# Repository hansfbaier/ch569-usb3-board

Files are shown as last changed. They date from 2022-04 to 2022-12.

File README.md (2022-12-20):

# CH569 USB3 Super Speed Board
USB3 super speed development board useful as FPGA expansion
based on the WCH-Tech CH569 chip.
It should also be possible to substitute the CH569 with a CH565 chip,
without further modifications.

### Board support
Open source development tools and board support package are available here:

https://github.com/orgs/hydrausb3/repositories

### Status
* rev0 tested and working
* rev1 tested and working
* rev2 tested and working. Passes stress test. Recommended!

NOTE: Both rev0 and rev1 have shown spurious transmission errors in USB3 stress tests.
Do not use for high performance duty. Adding a 100nF decoupling capacitor to the
3V3 pin of the crystal oscillator seemed to improve the situation significantly.





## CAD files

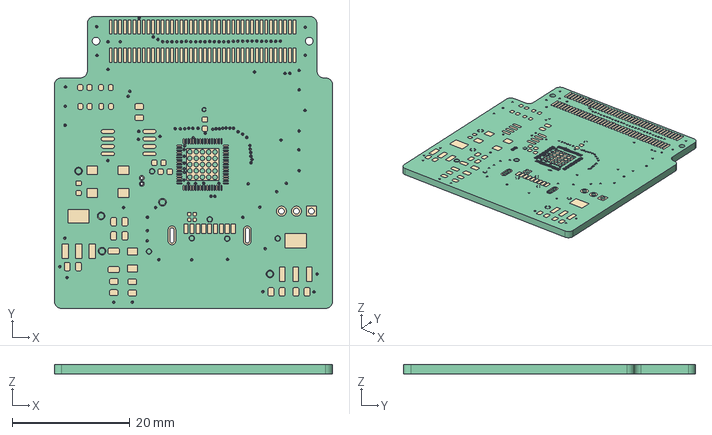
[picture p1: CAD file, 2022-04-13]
rev2/EdgeCuts.FCStd
47.3 x 49.6 x 1.62 mm
Pcb_12c2
topPads_12c2

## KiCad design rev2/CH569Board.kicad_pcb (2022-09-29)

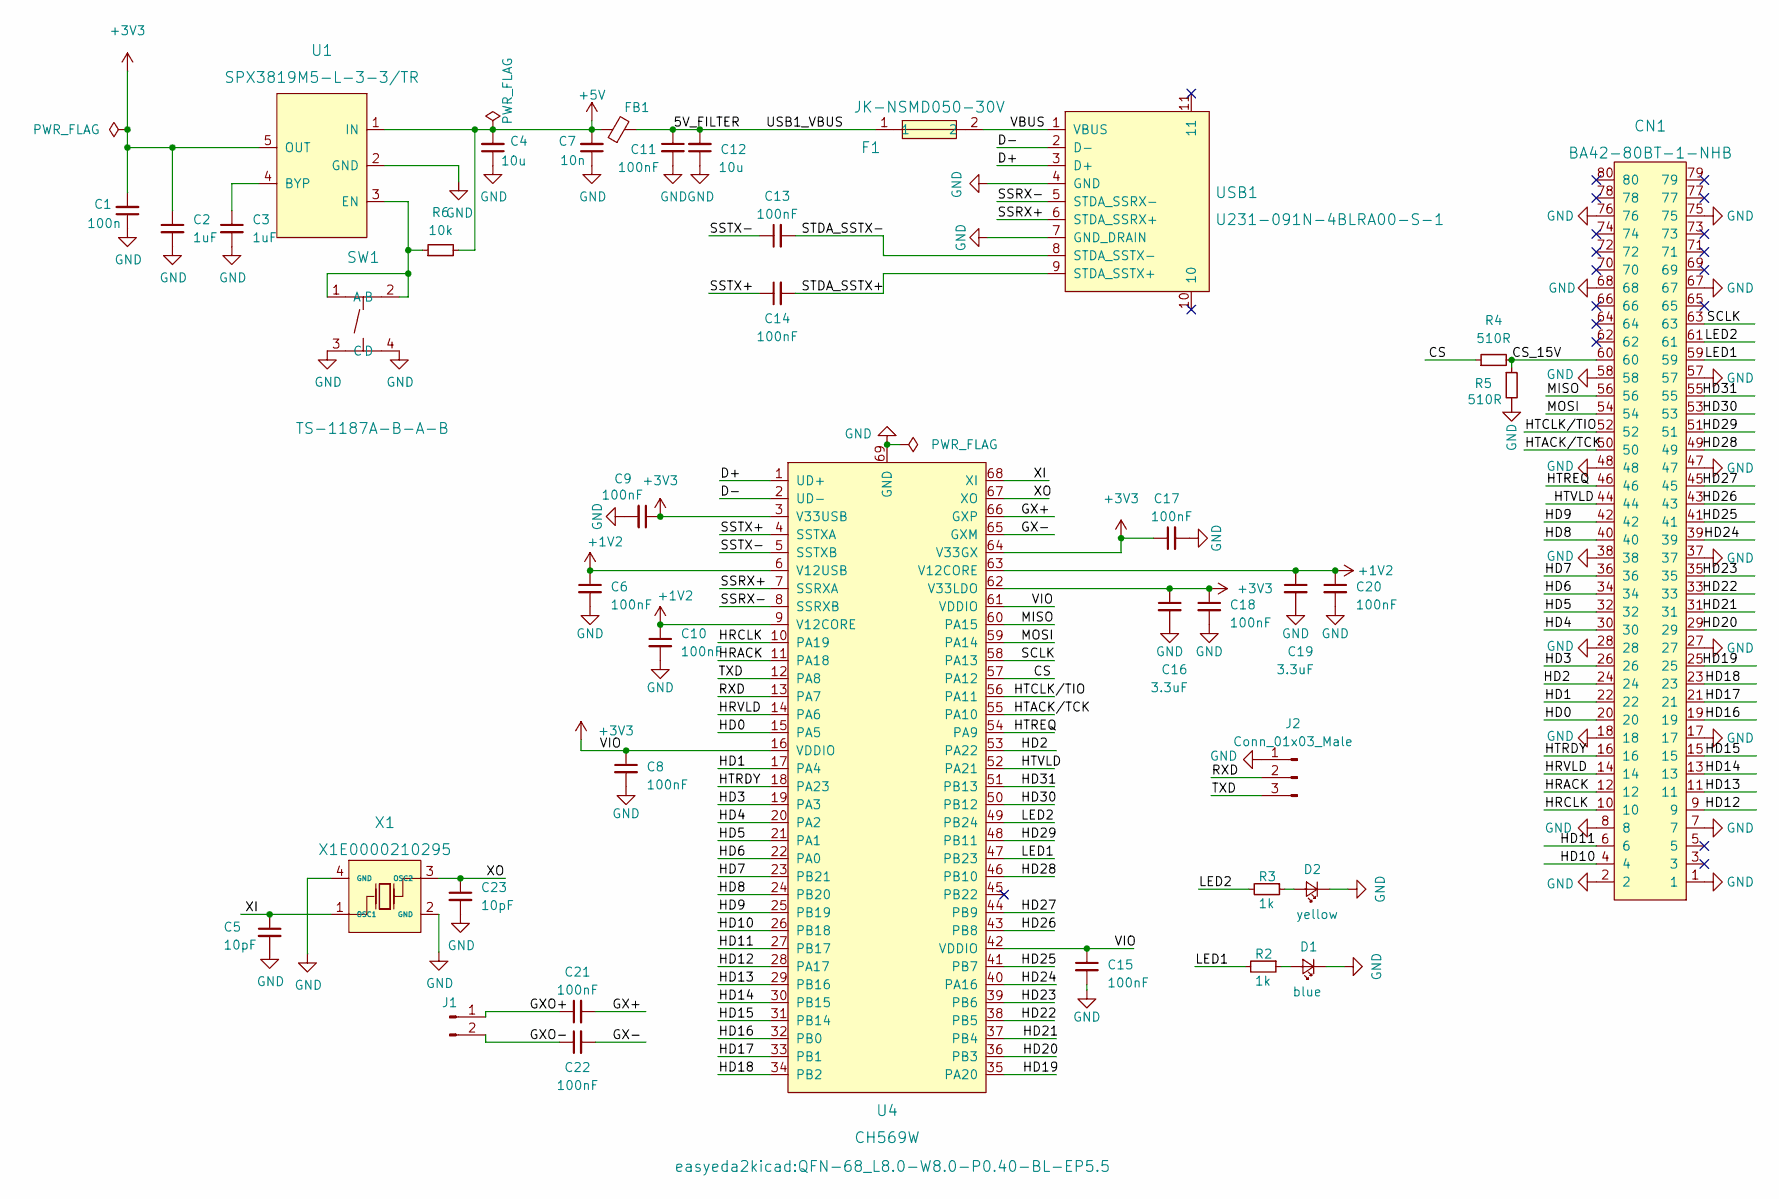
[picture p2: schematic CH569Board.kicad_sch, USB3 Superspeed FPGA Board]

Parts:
C1: 100n; C_0805_2012Metric; LCSC C49678
C2, C3: 1uF; C_0805_2012Metric; LCSC C28323
C4, C12: 10u; C_0805_2012Metric; LCSC C15850
C5, C23: 10pF; C_0402_1005Metric; LCSC C32949
C6, C8, C9, C10, C11, C17, C18, C20: 100nF; C_0805_2012Metric; LCSC C49678
C7: 10n; C_0805_2012Metric; LCSC C1710
C13, C14, C21, C22: 100nF; C_0402_1005Metric; LCSC C1525
C15: 100nF; C_0603_1608Metric; LCSC C14663
C16, C19: 3.3uF; C_0603_1608Metric; LCSC C51412
CN1: BA42-80BT-1-NHB; CONN-SMD_BA42-80BT-1-NHB; LCSC Part C508676
D1: blue; LED_0603_1608Metric; LCSC C72041
D2: yellow; LED_0603_1608Metric; LCSC C72038
F1: JK-NSMD050-30V; F1206; LCSC Part C720075
FB1: 2A; L_1206_3216Metric; LCSC C73732
J1: Conn_01x02_Male; PinHeader_1x02_P2.54mm_Vertical
J2: Conn_01x03_Male; PinHeader_1x03_P2.54mm_Vertical
R2, R3: 1k; R_0603_1608Metric; LCSC C21190
R4, R5: 510R; R_0402_1005Metric; LCSC C25123
R6: 10k; R_0402_1005Metric; LCSC C25744
SW1: TS-1187A-B-A-B; SW-SMD_4P-L5.1-W5.1-P3.70-LS6.5-TL-2; LCSC Part C318884
U1: SPX3819M5-L-3-3/TR; SOT-23-5_L3.0-W1.7-P0.95-LS2.8-BR; LCSC Part C9055
U4: CH569W; QFN-68_L8.0-W8.0-P0.40-BL-EP5.5; LCSC Part C2857462
USB1: U231-091N-4BLRA00-S-1; USB-A-SMD_U231-091N-4BLRA00-S-1; LCSC Part C381140
X1: X1E0000210295; CRYSTAL-SMD_4P-L3.2-W2.5-BL; LCSC Part C255930

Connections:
+1V2: C6.1, C10.1, C19.1, C20.1, U4.6 (V12USB), U4.9 (V12CORE), U4.63 (V12CORE)
+3V3: C1.2, C2.1, C8.1, C9.1, C15.1, C16.1, C17.1, C18.1, U1.5 (OUT), U4.3 (V33USB), U4.16 (VDDIO), U4.42 (VDDIO), U4.61 (VDDIO), U4.62 (V33LDO), U4.64 (V33GX)
+5V: C4.2, C7.2, FB1.1, R6.2, U1.1 (IN)
/5V_FILTER: C11.1, C12.2, F1.1, FB1.2
/CS: R4.1, U4.57 (PA12)
/CS_15V: CN1.60, R4.2, R5.1
/D+: U4.1 (UD+), USB1.3 (D+)
/D-: U4.2 (UD-), USB1.2 (D-)
/GX+: C21.2, U4.66 (GXP)
/GX-: C22.2, U4.65 (GXM)
/GXO+: C21.1, J1.1
/GXO-: C22.1, J1.2
/HD0: CN1.20, U4.15 (PA5)
/HD1: CN1.22, U4.17 (PA4)
/HD2: CN1.24, U4.53 (PA22)
/HD3: CN1.26, U4.19 (PA3)
/HD4: CN1.30, U4.20 (PA2)
/HD5: CN1.32, U4.21 (PA1)
/HD6: CN1.34, U4.22 (PA0)
/HD7: CN1.36, U4.23 (PB21)
/HD8: CN1.40, U4.24 (PB20)
/HD9: CN1.42, U4.25 (PB19)
/HD10: CN1.4, U4.26 (PB18)
/HD11: CN1.6, U4.27 (PB17)
/HD12: CN1.9, U4.28 (PA17)
/HD13: CN1.11, U4.29 (PB16)
/HD14: CN1.13, U4.30 (PB15)
/HD15: CN1.15, U4.31 (PB14)
/HD16: CN1.19, U4.32 (PB0)
/HD17: CN1.21, U4.33 (PB1)
/HD18: CN1.23, U4.34 (PB2)
/HD19: CN1.25, U4.35 (PA20)
/HD20: CN1.29, U4.36 (PB3)
/HD21: CN1.31, U4.37 (PB4)
/HD22: CN1.33, U4.38 (PB5)
/HD23: CN1.35, U4.39 (PB6)
/HD24: CN1.39, U4.40 (PA16)
/HD25: CN1.41, U4.41 (PB7)
/HD26: CN1.43, U4.43 (PB8)
/HD27: CN1.45, U4.44 (PB9)
/HD28: CN1.49, U4.46 (PB10)
/HD29: CN1.51, U4.48 (PB11)
/HD30: CN1.53, U4.50 (PB12)
/HD31: CN1.55, U4.51 (PB13)
/HRACK: CN1.12, U4.11 (PA18)
/HRCLK: CN1.10, U4.10 (PA19)
/HRVLD: CN1.14, U4.14 (PA6)
/HTACK/TCK: CN1.50, U4.55 (PA10)
/HTCLK/TIO: CN1.52, U4.56 (PA11)
/HTRDY: CN1.16, U4.18 (PA23)
/HTREQ: CN1.46, U4.54 (PA9)
/HTVLD: CN1.44, U4.52 (PA21)
/LED1: CN1.59, R2.2, U4.47 (PB23)
/LED2: CN1.61, R3.2, U4.49 (PB24)
/MISO: CN1.56, U4.60 (PA15)
/MOSI: CN1.54, U4.59 (PA14)
/RXD: J2.2, U4.13 (PA7)
/SCLK: CN1.63, U4.58 (PA13)
/SSRX+: U4.7 (SSRXA), USB1.6 (STDA_SSRX+)
/SSRX-: U4.8 (SSRXB), USB1.5 (STDA_SSRX-)
/SSTX+: C14.1, U4.4 (SSTXA)
/SSTX-: C13.1, U4.5 (SSTXB)
/STDA_SSTX+: C14.2, USB1.9 (STDA_SSTX+)
/STDA_SSTX-: C13.2, USB1.8 (STDA_SSTX-)
/TXD: J2.3, U4.12 (PA8)
/VBUS: F1.2, USB1.1 (VBUS)
/XI: C5.1, U4.68 (XI), X1.1 (OSC1)
/XO: C23.1, U4.67 (XO), X1.3 (OSC2)
GND: C1.1, C2.2, C3.2, C4.1, C5.2, C6.2, C7.1, C8.2, C9.2, C10.2, C11.2, C12.1, C15.2, C16.2, C17.2, C18.2, C19.2, C20.2, C23.2, CN1.1, CN1.2, CN1.7, CN1.8, CN1.17, CN1.18, CN1.27, CN1.28, CN1.37, CN1.38, CN1.47, CN1.48, CN1.57, CN1.58, CN1.67, CN1.68, CN1.75, CN1.76, D1.1 (K), D2.1 (K), J2.1, R5.2, SW1.3 (C), SW1.4 (D), U1.2 (GND), U4.69 (GND), USB1.4 (GND), USB1.7 (GND_DRAIN), X1.2 (GND), X1.4 (GND)
unnamed: C3.1, U1.4 (BYP)
unnamed: D1.2 (A), R2.1
unnamed: D2.2 (A), R3.1
unnamed: R6.1, SW1.1 (A), SW1.2 (B), U1.3 (EN)

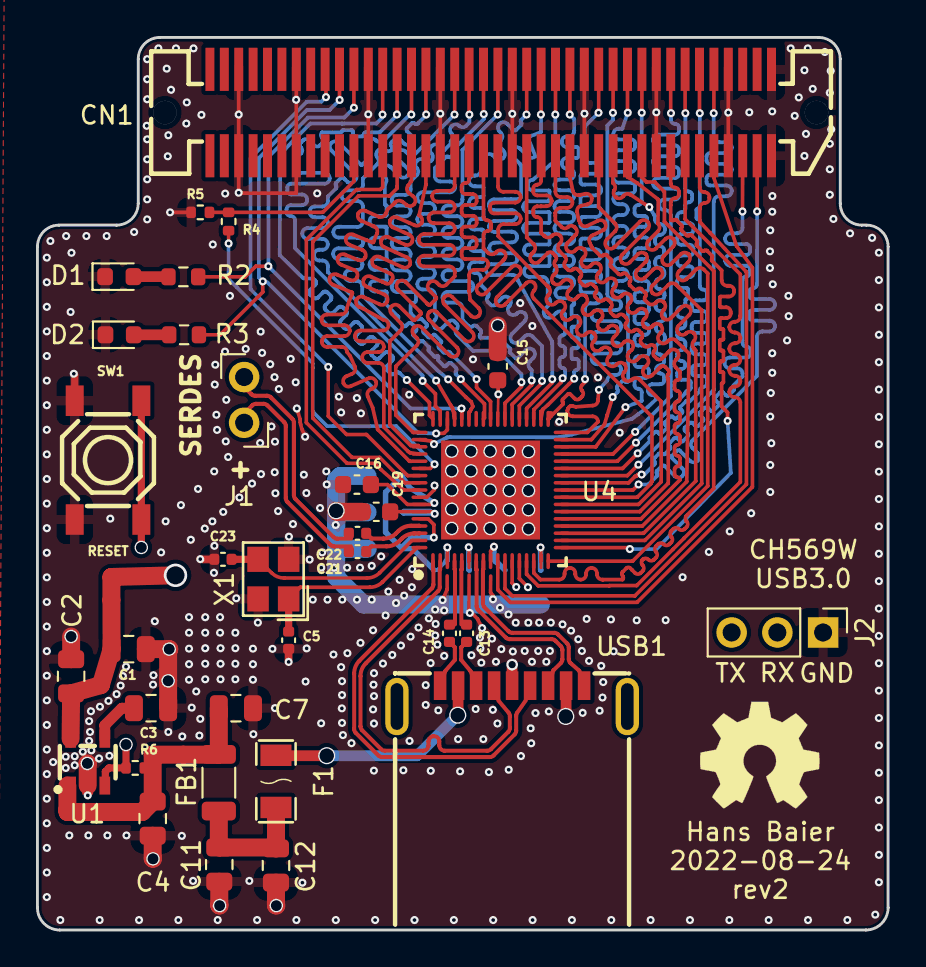
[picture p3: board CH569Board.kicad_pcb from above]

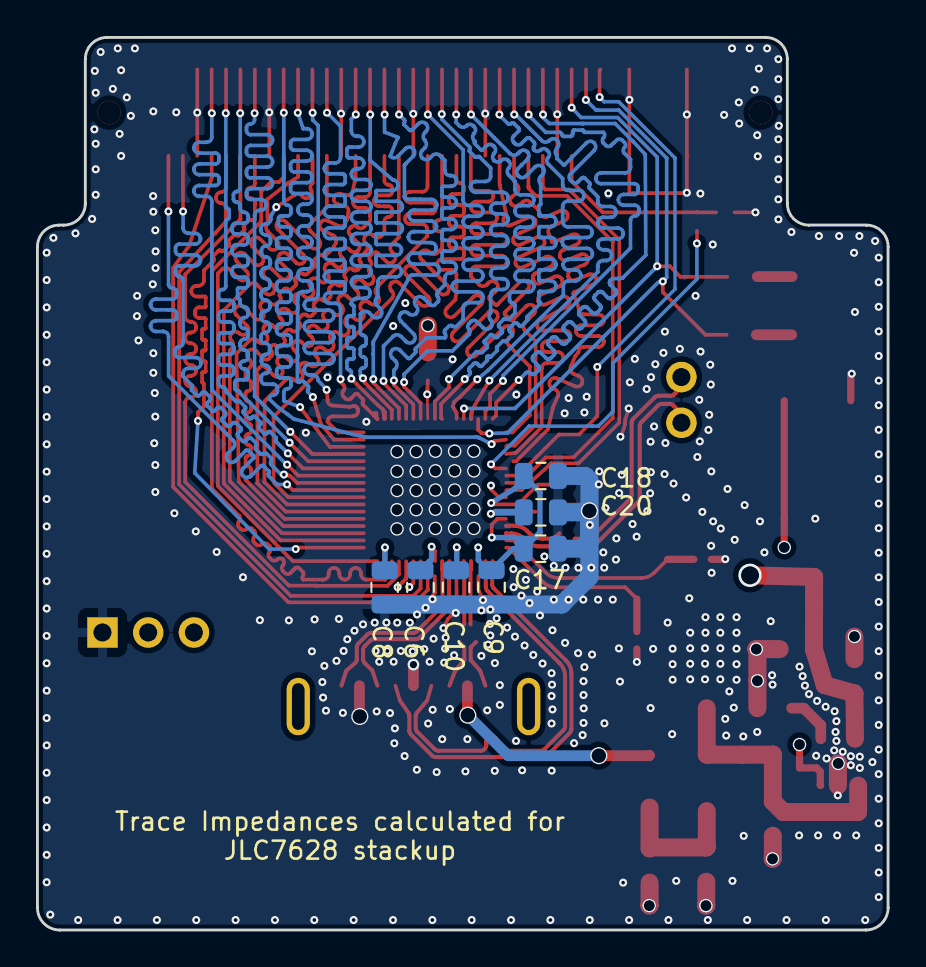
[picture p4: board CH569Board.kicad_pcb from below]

Board: 4 copper layers, 47.3 x 49.6 mm, 41 parts (7 on the bottom side), 73 nets.

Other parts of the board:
N1: OHWLOGO; OSHW-Symbol_6.7x6mm_SilkScreen

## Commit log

2022-04-09 add schematic
2022-04-12 New Edge cuts from FreeCAD and match the board to FPGA main board
    [CH569Board.kicad_pcb, CH569Board.kicad_sch, EdgeCuts.FCStd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]
2022-04-12 update production files
    [CH569Board-CuBottom.gbr, CH569Board-CuIn1.gbr, CH569Board-CuIn2.gbr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]
2022-04-13 Big design fixup: Make Layer 3 a GND plane so signals reference ground. Eliminate one LED for better integrity of the signal traces, new board outline
    [BOM-CH569Board.csv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]
2022-04-18 Fix swapped pins 1 and 3 on the 1.2V regulator
    [CH569Board-CuBottom.gbr, CH569Board-CuIn1.gbr, CH569Board-CuIn2.gbr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]
2022-04-22 add decoupling caps in serdes, layout improvements
    [BOM-CH569Board.csv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]
2022-04-22 move LEDs to a better place
    [CH569Board-CuBottom.gbr, CH569Board-CuIn1.gbr, CH569Board-CuIn2.gbr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]
2022-07-22 create rev0 subdirectory and move the first revision there
    [CH569Board.kicad_pcb, CH569Board.kicad_sch, CH569Board.sch]
2022-07-23 board revision 1
    [BOM-CH569Board.csv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]
2022-07-23 fix U2 silkscreen
    [CH569Board.kicad_pcb]
2022-07-23 export fixes to production files
    [CH569Board-CuBottom.gbr, CH569Board-CuIn1.gbr, CH569Board-CuIn2.gbr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]
2022-08-11 fix important flaw in rev1: 3.3V and VIO were not connected
    [CH569Board-CuBottom.gbr, CH569Board-CuIn1.gbr, CH569Board-CuIn2.gbr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]
2022-08-22 remove 1V2 regulator, create HSPI netclass, rewire 1V2 power net
    [CH569Board.kicad_pcb, CH569Board.kicad_sch, CH569Board.sch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]
2022-08-22 fix high speed tracks, move crystal closer, clean up power supply traces
    [CH569Board.kicad_pcb]
2022-08-22 Some finishes. Put OSHW logo on silkscreen
    [CH569Board.kicad_pcb]
2022-08-23 redo power section with different LDO, add decoupling cap and reset switch
    [CH569Board.kicad_pcb, CH569Board.kicad_sch]
2022-08-23 stitch board edges and add more ground vias
    [CH569Board.kicad_pcb]
2022-08-23 rev2 ready for the fab. used a crystal instead of an XO, because of better specs
    [CH569Board-CuBottom.gbr, CH569Board-CuIn1.gbr, CH569Board-CuIn2.gbr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]
2022-08-23 move ground via closer to cap
    [CH569Board.kicad_pcb]
2022-09-29 fix Pin64 short to ground and missing decoupling cap connection
    [CH569Board-CuBottom.gbr, CH569Board-CuIn1.gbr, CH569Board-CuIn2.gbr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]
